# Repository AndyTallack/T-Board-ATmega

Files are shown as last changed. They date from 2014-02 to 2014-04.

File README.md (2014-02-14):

T-Board-ATMega
==============

T-Board for use on Breadboard - ATMega 328

This is a series of boards to speed up development of your own standalone ATMega/ATTiny projects.  The T-Board houses the microprocessor, power-supply and FTDI interface, with a breadboard-compatible footprint.  This allows you to get up and running fast with the core ATMega/ATTiny "heart" of your project.

This board is based on the great Arduino concept, and is compatible with the Arduino IDE.  It differs in that it:
- allows you to switch between 3.3V and 5V
- allows you to select crystals for low-power applications
- fits snugly into a breadboard, keeping your project together

There are 2 sets of schematic:
- T-Board-328 Etch:	1-layer, for hand-etching.  No ICSP header
- T-Board-328 PCB:	2-layer, for production-house.  With ICSP header

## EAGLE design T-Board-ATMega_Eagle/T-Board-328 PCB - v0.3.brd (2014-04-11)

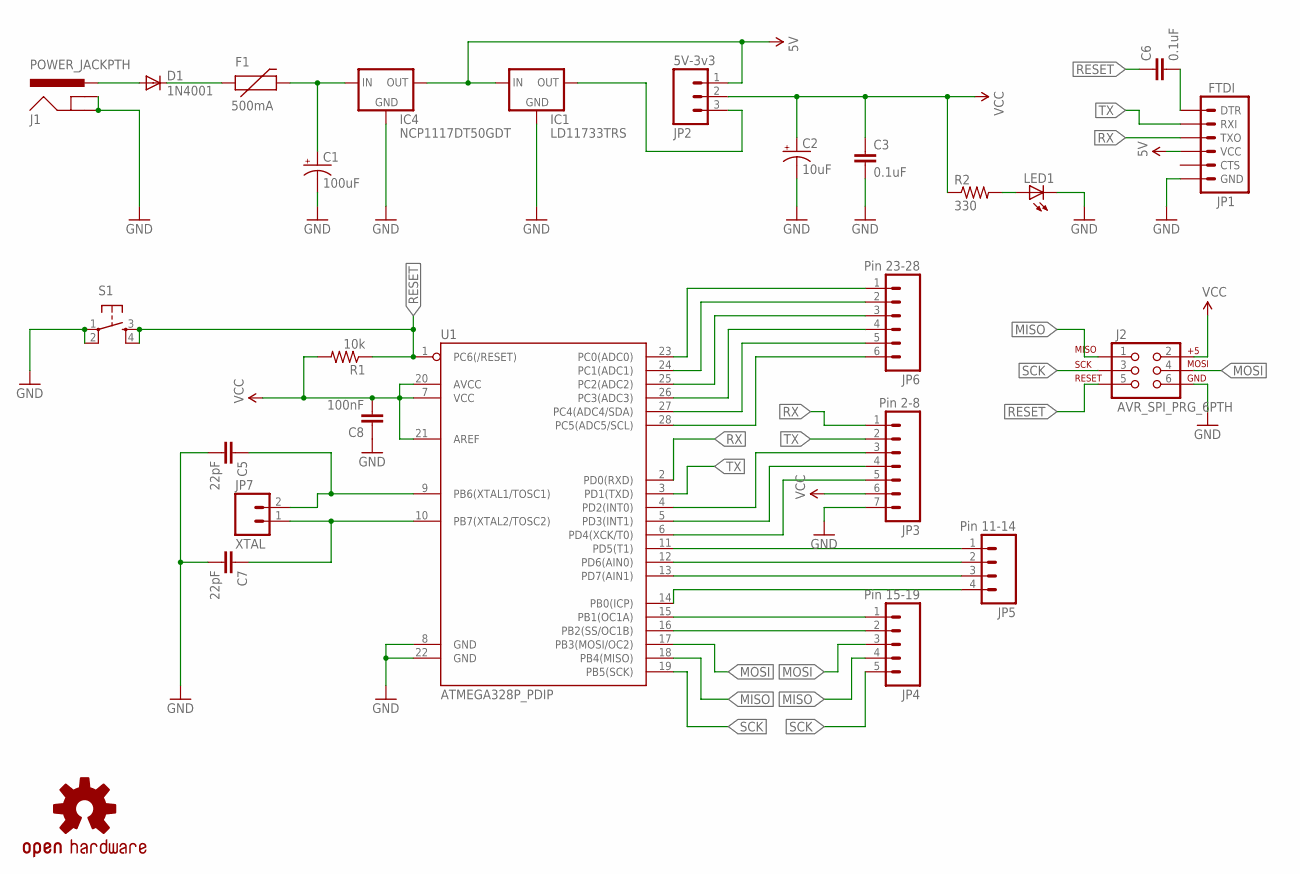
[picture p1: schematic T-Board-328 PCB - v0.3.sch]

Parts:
C1: 100uF; CPOL-RADIAL-100UF-25V
C2: 10uF; CPOL-RADIAL-10UF-25V
C3, C6: 0.1uF; 1206
C5, C7: 22pF; 1206
C8: 100nF; 1206
D1: 1N4001; DIODE-1N4001
F1: 500mA; PTC
IC1: LD11733TRS; SOT223
IC4: NCP1117DT50GDT; DPACK
J1: POWER_JACKPTH; POWER_JACK_PTH
J2: AVR_SPI_PRG_6PTH; 2X3
JP1: FTDI; 1X06_LONGPADS
JP2: 5V-3v3; 1X03
JP3: Pin 2-8; 1X07
JP4: Pin 15-19; 1X05
JP5: Pin 11-14; 1X04
JP6: Pin 23-28; 1X06
JP7: XTAL; 1X02
LED1: LED1206; LED-1206
LOGO1: OSHW-LOGOS; OSHW-LOGO-S
R1: 10k; 1206
R2: 330; 1206
S1: TAC_SWITCHPTH; TACTILE-PTH
U1: ATMEGA328P_PDIP; DIL28-3

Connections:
5V: IC1.3 (IN), IC4.4 (OUT), JP1.4 (VCC), JP2.1
GND: C1.2 (-), C2.2 (-), C3.2, C5.2, C7.2, C8.1, IC1.1 (GND), IC4.1 (GND), J1.GND, J1.GNDBREAK, J2.6, JP1.6 (GND), JP3.7, LED1.C, S1.1, S1.2, U1.8 (GND), U1.22 (GND)
MISO: J2.1, JP4.4, U1.18 (PB4(MISO))
MOSI: J2.4, JP4.3, U1.17 (PB3(MOSI/OC2))
unnamed: D1.A, J1.PWR
unnamed: JP6.1, U1.23 (PC0(ADC0))
unnamed: D1.C, F1.P$1 (1)
unnamed: C1.1 (+), F1.P$2 (2), IC4.3 (IN)
unnamed: JP6.2, U1.24 (PC1(ADC1))
unnamed: C6.2, JP1.1 (DTR)
unnamed: C7.1, JP7.1, U1.10 (PB7(XTAL2/TOSC2))
unnamed: C5.1, JP7.2, U1.9 (PB6(XTAL1/TOSC1))
unnamed: LED1.A, R2.2
unnamed: IC1.4 (OUT), JP2.3
unnamed: JP5.1, U1.11 (PD5(T1))
unnamed: JP5.2, U1.12 (PD6(AIN0))
unnamed: JP5.3, U1.13 (PD7(AIN1))
unnamed: JP5.4, U1.14 (PB0(ICP))
unnamed: JP4.1, U1.15 (PB1(OC1A))
unnamed: JP4.2, U1.16 (PB2(SS/OC1B))
unnamed: JP6.3, U1.25 (PC2(ADC2))
unnamed: JP6.4, U1.26 (PC3(ADC3))
unnamed: JP6.5, U1.27 (PC4(ADC4/SDA))
unnamed: JP6.6, U1.28 (PC5(ADC5/SCL))
unnamed: JP3.3, U1.4 (PD2(INT0))
unnamed: JP3.4, U1.5 (PD3(INT1))
unnamed: JP3.5, U1.6 (PD4(XCK/T0))
RESET: C6.1, J2.5, R1.1, S1.3, S1.4, U1.1 (PC6(/RESET))
RX: JP1.3 (TXO), JP3.1, U1.2 (PD0(RXD))
SCK: J2.3, JP4.5, U1.19 (PB5(SCK))
TX: JP1.2 (RXI), JP3.2, U1.3 (PD1(TXD))
VCC: C2.1 (+), C3.1, C8.2, J2.2, JP2.2, JP3.6, R1.2, R2.1, U1.7 (VCC), U1.20 (AVCC), U1.21 (AREF)

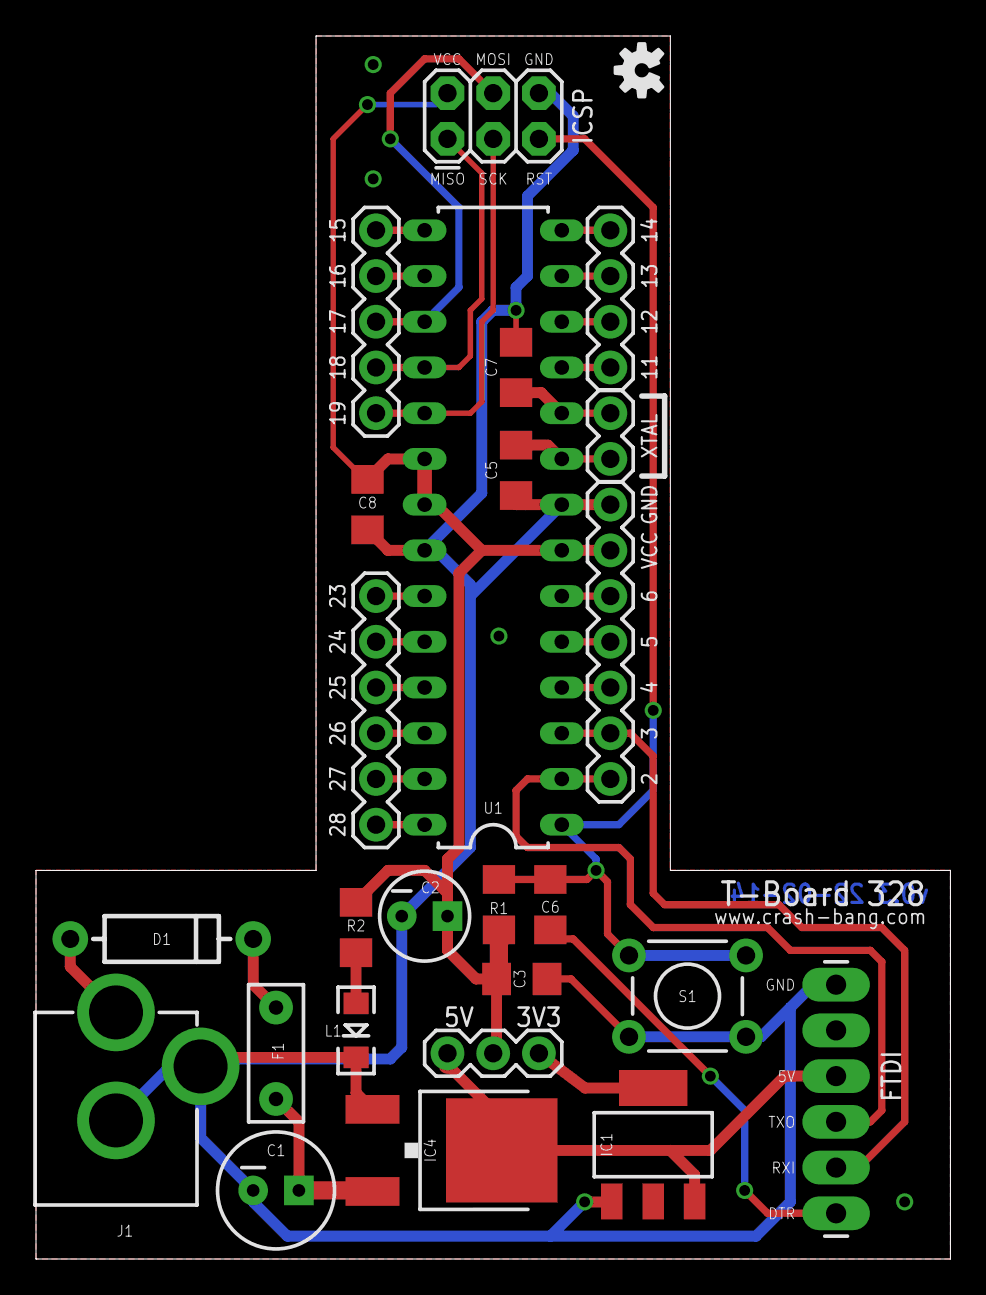
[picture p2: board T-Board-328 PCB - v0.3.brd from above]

Board: 2 copper layers, 50.8 x 67.9 mm, 26 parts (0 on the bottom side), 32 nets.

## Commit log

2014-02-14 v0.3 - First pre-release
    [T-Board-328 Etch - v0.3.brd, T-Board-328 Etch - v0.3.sch, T-Board-328 PCB - v0.3.brd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]
2014-03-16 v0.4 - Second Prototype
    Second prototype sent to OSHPark for fab.
    - Reduced footprint
    - Corrected mirrored voltage regulators
    - Corrected unconnected capacitor
    [T-Board-328 PCB - v0.3.brd, T-Board-328 PCB - v0.3.sch]
2014-04-11 Adjusted header pins
    Header pins spacing corrected to fit breadboard more precisely
    [T-Board-328 PCB - v0.3.brd]

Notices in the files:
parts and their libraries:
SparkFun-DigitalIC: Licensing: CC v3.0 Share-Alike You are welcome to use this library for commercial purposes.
